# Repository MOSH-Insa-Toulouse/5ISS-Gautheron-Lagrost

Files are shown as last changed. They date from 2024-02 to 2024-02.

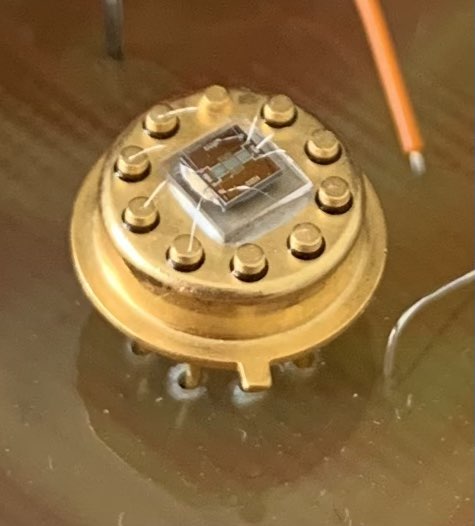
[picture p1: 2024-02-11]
__Images/sensor.jpg

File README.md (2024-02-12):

# Creating a shield to send data from a SGS24ISS gas sensor to a LoRaWAN Network

Authors: Arthur Gautheron, Olivier Lagrost

## 📝 Objectives and Block Diagram

The final objective of the Smart Devices UF is to "design and build a smart device based on the combination of a gas sensor and an electronic card to communicate information over a low speed network". It is a pluridisciplinary subject that combines skills from all educational backgrounds included in the PTP. GP (physics) students are best at designing a PCB and creating datasheets. AE (electronics) students, such as ourselves, prefer electrical schematics, embedded programming and have a better understanding of how to design the whole system overall. Finally, IR (computer science) students are better at understanding how to communicate data over LoRaWAN.

This repository aims at explaining our work on this system.

SGS24ISS is the name we decided to give to our homemade gas sensor. It stands for "Smart Gas Sensor 2024 Innovative Smart Systems". The objective of the project is to collect data from the smart sensor, monitor its internal temperature for optimal measurements, and send the collected data over LoRa to a Chirpstack server to be processed and used in an eventual application.

MOSH_diagram

## 🧑‍🔬 Sensor design and creation

sensor

The SGS24ISS gas sensor is capable of detecting the presence of several gases depending on their concentration. The sensor is able to perform multiple tasks:
* Returns current that depends on the concentration of gas around the sensor.
* Measure its own internal temperature.
* Increase its own temperature with an integrated heater.

For more information about the sensor, please read its datasheet [here](https://github.com/Timanoin/lora_app/blob/main/datasheet.pdf).

## 💻 Sensor Acquisition System



To collect data from the sensor, the current emitted by the sensor must be transformed into voltage, since MCUs cannot acquire current intensity. The system developed to acquire this information is a transimpedance amplifier.
The LTSpice directory contains the schematic of such an acquisition system, as well as other simulations to model the gas sensor.

The transimpedance amplifier is composed of 4 stages.
* Low-pass filter of cut-off frequency 16Hz to remove noise from the sensor.
* Low-pass filter of cut-off frequency 1.6Hz to remove noise from the mains supply.
* Non-inverting amplifier.
* Low-pass filter of cut-off frequency 1600Hz as an anti-aliasing filter.

The resistance of the gas sensor is determined as follows:


## ✏️ Shield Electrical Schematic



The schematics tested in simulation with LTSpice are recreated into KiCad for future PCB creation. All pins from the SGS24ISS (gas sensor, temperature sensor, heater) are connected to the Arduino pins. The RN2483 LoRa communication chip and its antenna are also connected to the Arduino in the schematic.
The KiCad files can be found here.

## ⚡ Shield PCB Design



The PCB is routed on the bottom layer, since pins of THT components must be soldered on the copper covered side of the PCB.

moshpcb

The resulting PCB is pretty small, but it could be even smaller if another MCU was used for data acquisition (like an Arduino Nano or a STM32).

## 💻 Arduino Uno Embedded Software



We first set up our LoRa communication and we initialize the pins for the sensor and the Uart to communicate with our chip. Thus we have two serial communications, “Serial” between the computer and the Arduino and “mySerial” between the Arduino and the RN2483A. We also define the threshold on the sensor value above which we start transmitting our data, meaning that the gas quantity is dangerous. 



In order to communicate by LoRa we have to set it up. We wait for our RN2483A to start and check if we can communicate by LoRa. To this end, we print the Hardware EUI (HWEUI) which is the ID of our RN2483 and that we need to register our device on Chirpstack. 



We now have to establish communication with Chirpstack using the Over The Air Authentication (OTAA) method to connect to the network. To this end, we need the appEui and the appKey found on the Chirpstack website when registering our device. and the function ”initOTAA(appEui, appKey)” to connect. 

## 📻 ChirpStack





On the Chirp Stack side, we create a profile and add a device to get the JoinEui ( = appEui) and the appKey. 
Once we are connected we can start sending the data from our sensor. 
As specified at the beginning, we only send data when an overshoot to the threshold happens. 



We can see that we are connected to Chirpstack, our device is enabled and sending data in ASCII

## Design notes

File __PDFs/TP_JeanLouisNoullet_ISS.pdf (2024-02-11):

# ISS - UF Smart Devices : partie analogique

English version here

## 1. Mesure d'une résistance

Méthodes classiques :

- imposer I, mesurer V
- imposer V, mesurer I
- alimenter, mesurer V et I
- alimenter, mesurer R par identification (pont)

Cas du capteur de gaz à nano-particules :

- très faible courant : de l'ordre de 100 nA
- effet tunnel : forte non-linéarité de I(V)

Alors quelle technique adopter pour extraire l'information utile du capteur ?

## 2. Mesure de faible courant avec un micro-contrôleur

Parametres des microcontrôleurs courants en 2016
(AVR/Arduino, STM32, PIC Microchip, etc...) :
- résolution 10 à 12 bits (1024 à 4096 points)
- pleine échelle (VRef) de 1.1 V à 5.0 V
- impédance de source max 1 kOhm à 10 kOhm
- fréquence d'échantillonnage max 15 kHz à 2.4 MHz
La mesure directe d'un courant de 100 nA ne parait pas praticable.
N.B. la valeur max d'impédance de source est spécifiée en fonction de l' échantillonneur à capacité commutée présent à l'entrée de l'ADC.

Solution "classique" :

L'amplificateur transimpédance.

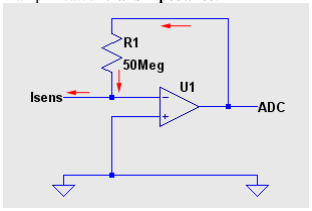
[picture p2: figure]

Problèmes posés par cette solution :

- nécessite une très grande valeur pour R1
- nécessite une tension négative pour alimenter le capteur

Solution "classique" améliorée :

L'amplificateur transimpédance suivi d'un étage amplificateur inverseur.

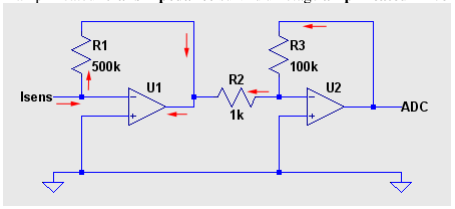
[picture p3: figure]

- grâce au gain du second étage, la résistance R1 n'a pas besoin d'être grande
- grâce à l'inversion, l'alimentation du capteur peut être positive
- cependant il faut une alimentation bipolaire pour les amplis

Solution minimaliste :

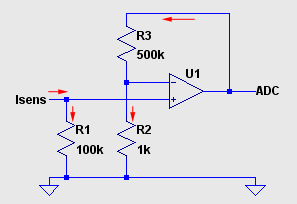
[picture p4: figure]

- conversion I-->U dans la résistance d'épreuve R1 (shunt)
- amplification à fort gain par montage non-inverseur
- la chute de tension sur R1 perturbe (un peu) la tension appliquée au capteur
- peut fonctionner avec seulement une alimentation positive

Remarques :
Gain de l’étage de l’AOP : (R2+R3)/R2=(1k+500k)/1k=501
Tension aux bornes de R1 : le courant Isens est d’environ 100nA
- V = 100kOhm*100nA=10⁻²V=10mV
Tension sur l’ADC : Gain*Tension aux bornes de R1 => 501*10x10⁻³~5V

Contraintes sur le choix de l'ampli :

- faible courant d'entrée

- ultra-faible offset de tension
- supporte mode commun à la tension d'alim négative ("low rail")

Remarques :
(1) offset voltage = erreur constante aux entrées de l’amplificateur différentiel dû à un état non compensé sur l’étage d’entrée de l’amplificateur. On veut que cet offset soit négligeable devant la tension mesurée sur R1 qui sera de 10mV.
(2) Le courant d’entrée doit être très petit devant Isens pour avoir le Isens traverse la R1 et pas l’entrée
(3) Mode commun : tension commune aux deux entrées, un bon amplifieur sera insensible à ce mode commun. Si le Isens =0A ,on veut 0V sur l’ADC. LTC1050C => 5µV offset voltage, et maximum offset voltage drift : 0.05µV/°C. Bien comparé aux 10mV aux bornes de R1.

L'ampli LTC1050C est disponible, satisfait-il ces contraintes ?

## 3. Filtrage passe-bas

Une bande passante de l'ordre de 1 Hz est largement suffisante pour extraire toute l'information utile du capteur, dont l'inertie est importante.

Un montage aussi sensible étant très vulnérable au bruit à 50Hz (+ harmoniques) résultant du couplage capacitif avec le réseau 230V, un filtrage passe-bas est indispensable.
D'autres sources de bruit à filtrer sont les horloges de circuits digitaux (microcontrôleur, afficheurs, etc...) et les transceivers RF (bluetooth, etc...).

Ce filtrage peut être effectué en partie du coté digital, par programme, sur le microcontrôleur.
Cependant un filtrage analogique est indispensable, en effet un excès de bruit à l'entrée de l'ADC pourrait amener celui-ci à saturation.
De plus un filtrage anti-repliement (anti-aliasing) est indispensable en raison de l'échantillonnage effectué par l'ADC.
Pour faciliter ce filtrage on a intérêt à faire fonctionner l'ADC à la plus GRANDE fréquence utilisable SANS PERTE DE QUALITE (dans le cas de l'Arduino Uno, 200kHz/13 = 15.4 kHz, avec un choix de prescaler à 128 ! (cf wiring.c).

Le filtrage peut s'implanter dans 3 régions de la chaîne de traitement analogique :

- filtre passif à l'entrée : permet d'éviter que les bruits HF causent de la distorsion dans les étages d'entrée
- filtre actif basé sur les amplificateurs opérationnels : maximum d'efficacité
- filtre passif en fin de chaine, coté ADC, pour retirer le bruit introduit en cours de traitement (bruit d'alimentation, bruit d'horloge des amplificateurs à découpage)

Schéma Suggéré

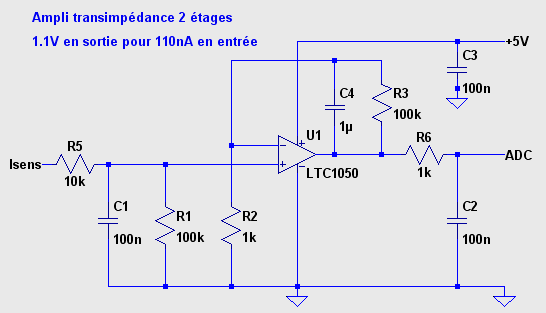
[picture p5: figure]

- R5 en entrée protège l'ampli opérationnel contre les décharges électrostatiques, en forme avec C1 un filtre pour les bruits en tension
- C1 avec R1 forme un filtre pour le bruit en courant
- R2 sera interchangeable, pour permettre une adaptation du calibre
- C4 avec R3 forme un filtre actif
- C2 avec R6 forme le filtre de sortie
- C3 filtre le bruit d'alimentation

## 4. Questions

A l’aide du simulateur LTSpice IV :

1. Vérifier la fonctionnalité dans les conditions nominales 2. L'incidence de l'offset de l'amplificateur LTC1050C est-elle acceptable ? 3. L'incidence du courant d'entrée de l'amplificateur est-elle acceptable ? 4. Quelle est la fréquence de coupure de chaque étage de filtre passe-bas ? 5. Quelle est l'atténuation globale d'un bruit en courant de 50 Hz ?

6. Quelle est l'atténuation globale d'un bruit en courant à la fréquence limite de repliement (dans le cas de l'ADC Arduino Uno) ?

### 7. Préparez une simulation de démonstration avec :

- un capteur alimenté en 5V dont la conductance varie de 10 nS à 20 nS en 0.5s (l’utilisation d’un filtre passe-bas pourrait être utile !).

### 1. Mettre en évidence l’intérêt du filtrage 50Hz choisi en visualisant

l’impact d’un bruit de 1% sur la source d’alimentation du capteur

### 2. Quand est-ce que ce bruit devient gênant ?

- Pour s’approcher des conditions réelles de mesures réalisées à l’AIME, vous modifierez le montage précédent pour mettre une alimentation de 20V sur le capteur (à la place de la 5V) et conserverez l’alimentation de 5V sur l’AOP.

### 1. Peut-on réaliser ce montage sur un Arduino Uno ?

- une source de bruit de 230V RMS à 50Hz, couplée au noeud d'entrée par une capacité de 1 pF
- Serait-il intéressant d’ajouter un montage dérivateur pour mesurer directement le coefficient cinétique de la réaction chimique du capteur avec un gaz ?

### 1. Si oui, proposez un montage !

N.B. pour simuler une conductance variable, utiliser l'élément Arbitrary current source (symbole BI) de LTSpice contrôlé par une source de tension indépendante représentant la variation de concentration du gaz atteignant le capteur

8. Donner une expression analytique de la résistance du capteur en fonction des éléments du circuit transimpédance.

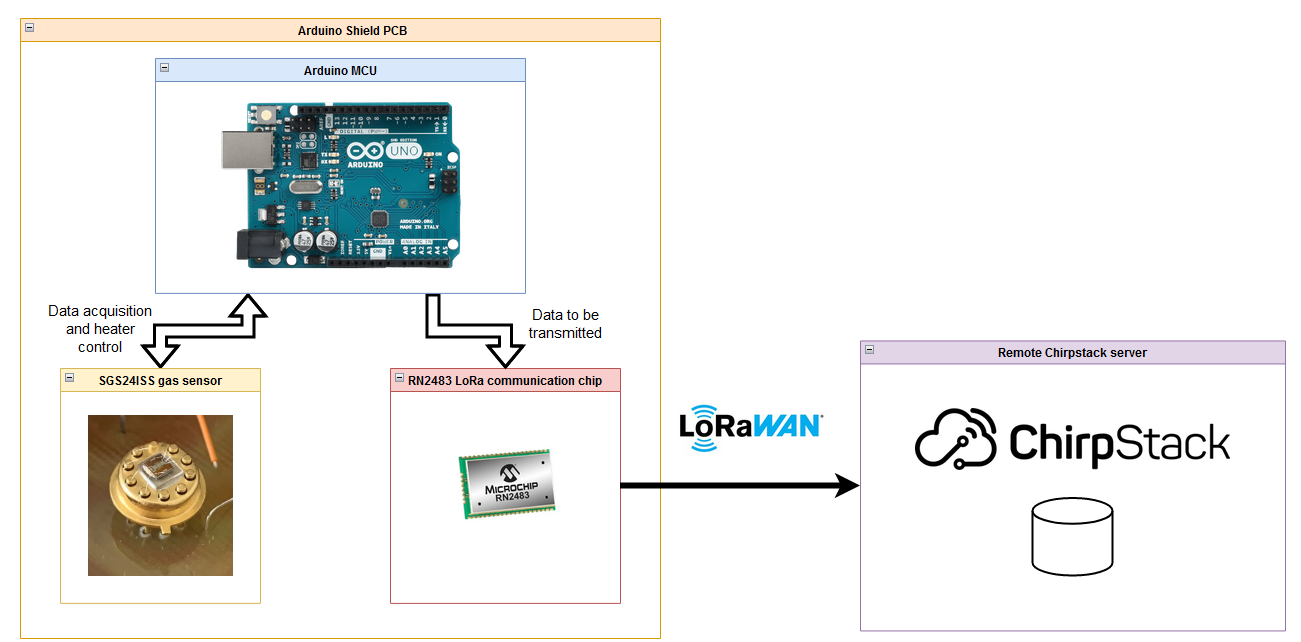
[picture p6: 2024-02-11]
__Images/MOSH_diagram.png

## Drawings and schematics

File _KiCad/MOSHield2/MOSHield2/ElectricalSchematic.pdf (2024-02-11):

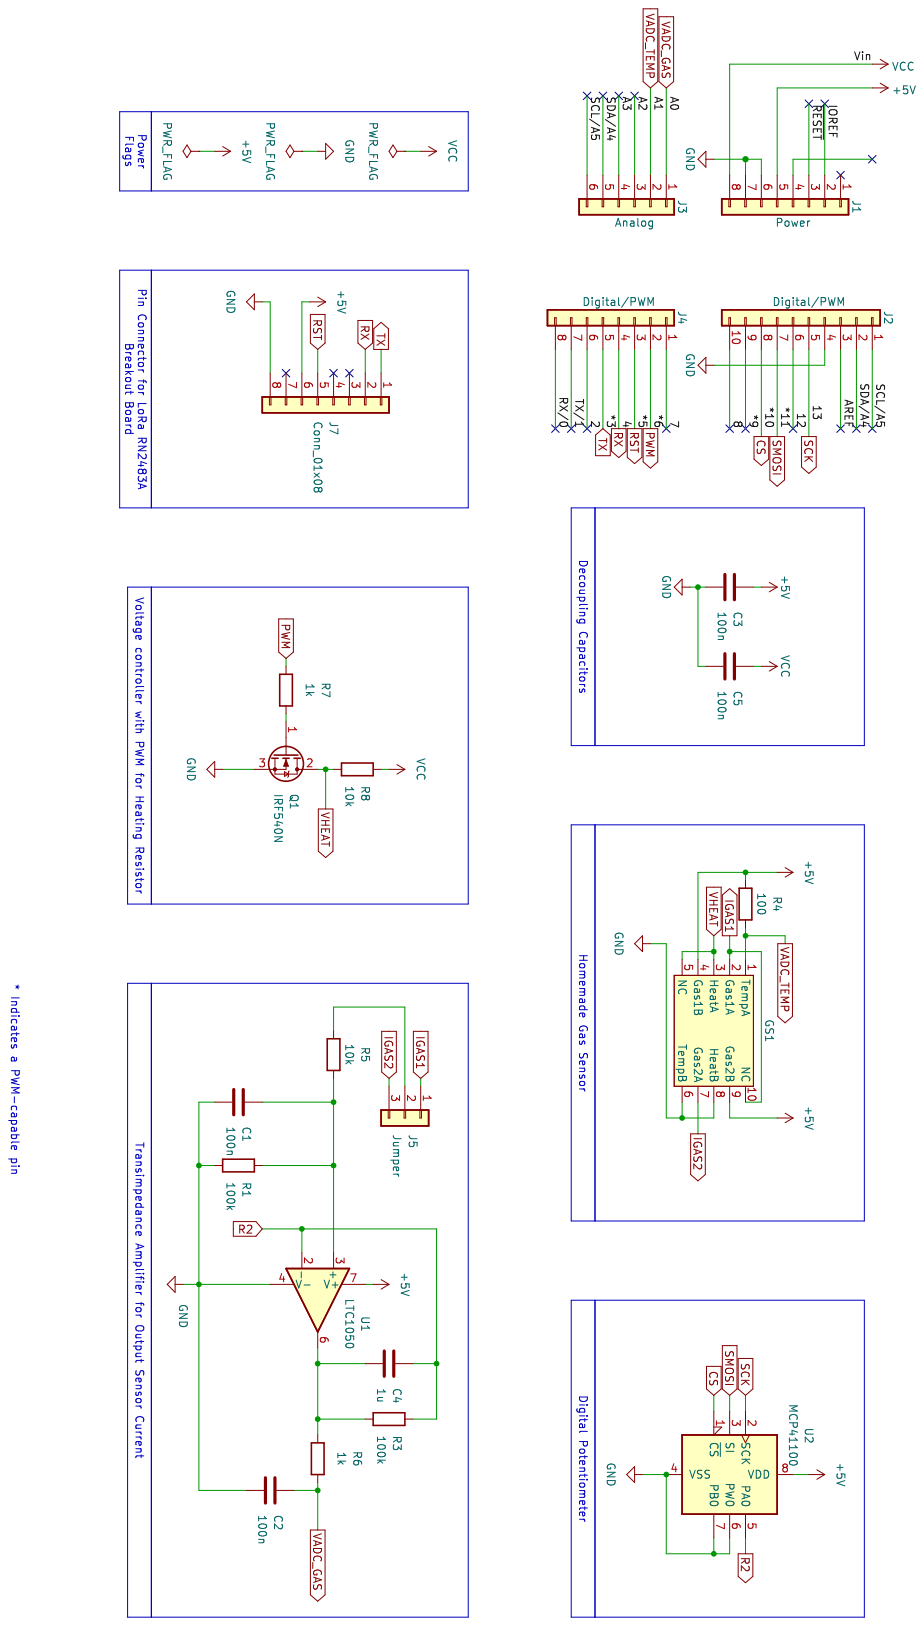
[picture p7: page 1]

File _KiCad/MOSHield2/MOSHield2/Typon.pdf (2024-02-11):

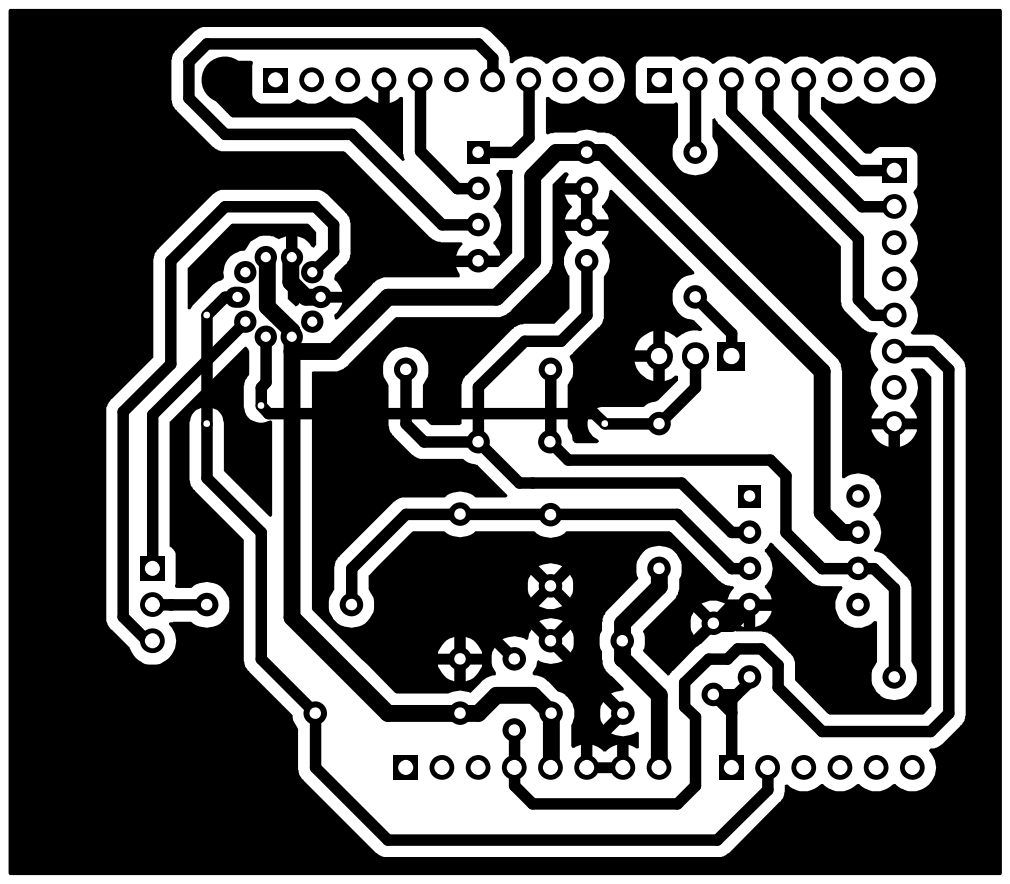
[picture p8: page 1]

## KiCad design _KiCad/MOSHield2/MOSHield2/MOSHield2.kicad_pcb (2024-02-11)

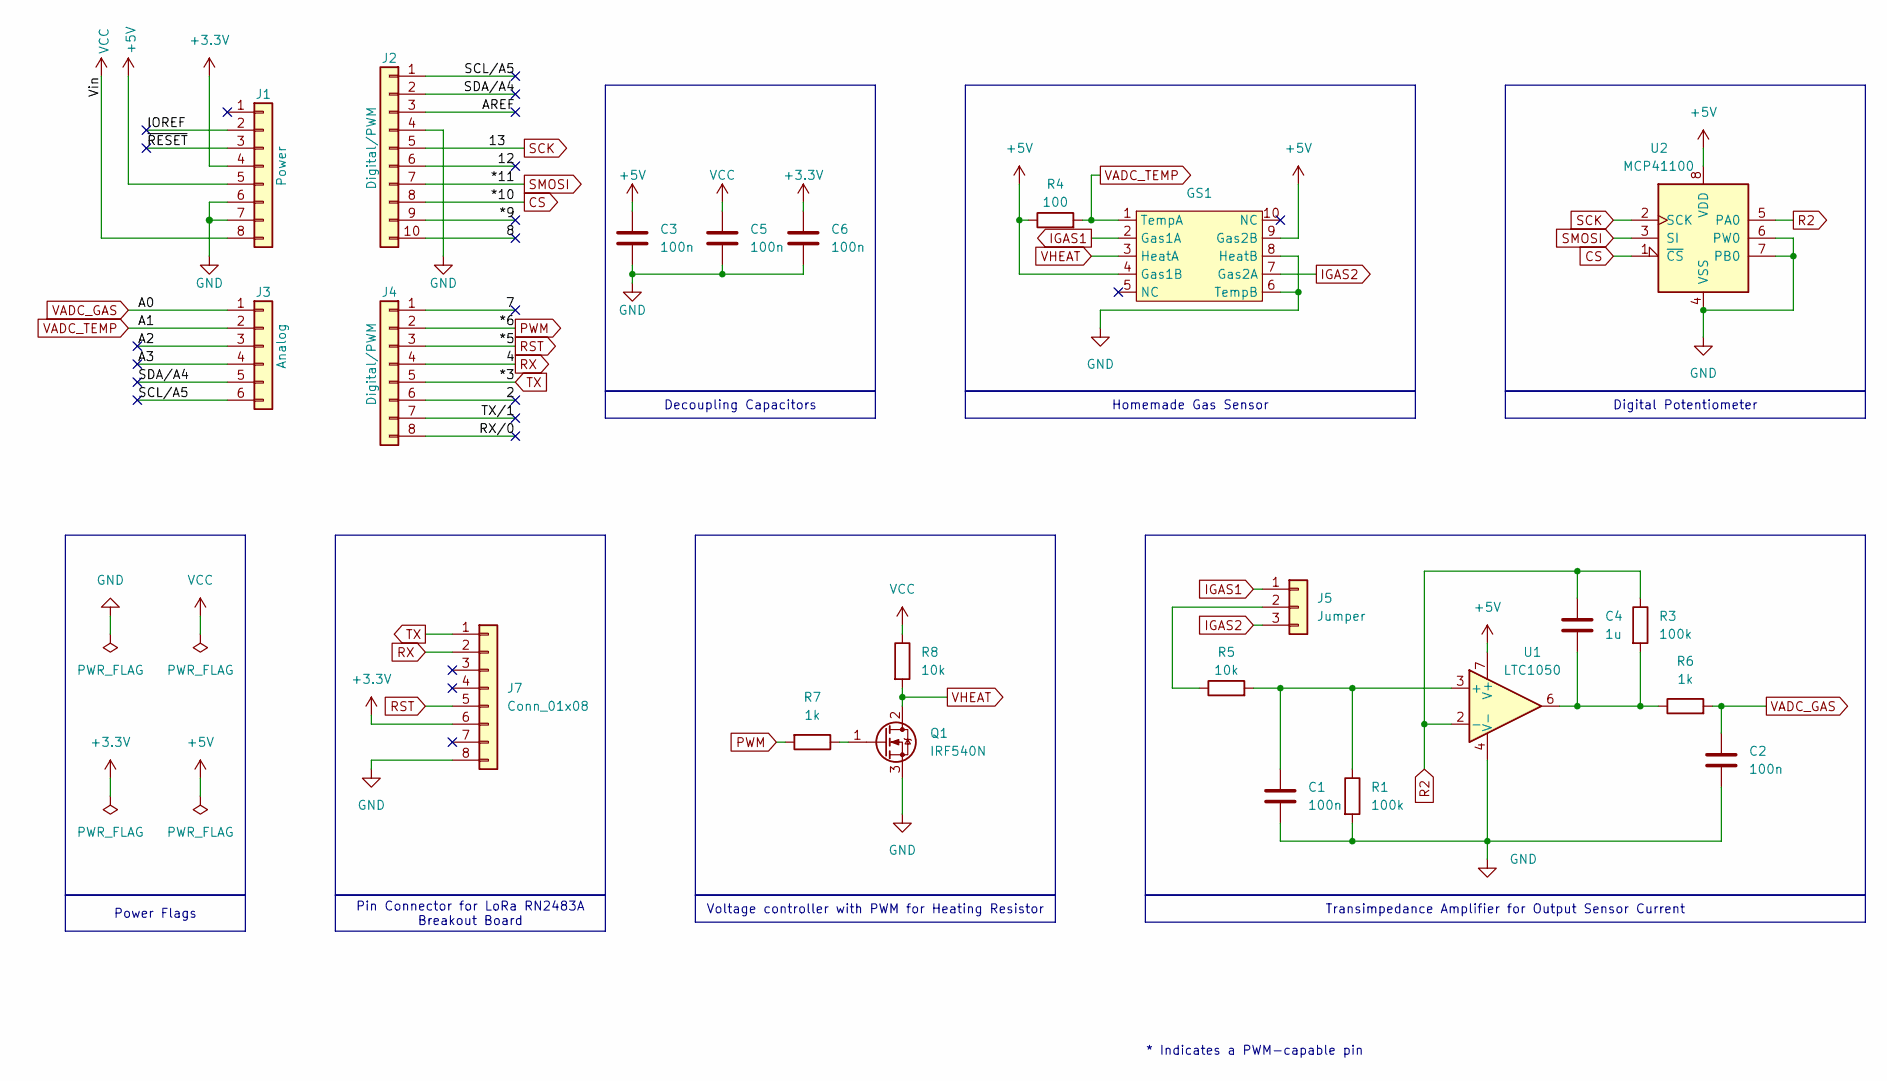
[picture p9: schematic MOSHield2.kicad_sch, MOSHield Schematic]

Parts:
C1, C2, C3, C5, C6: 100n; C_Disc_D4.7mm_W2.5mm_P5.00mm
C4: 1u; C_Rect_L7.0mm_W4.5mm_P5.00mm
GS1: TO-5-10
J1: Power; PinSocket_1x08_P2.54mm_Vertical
J2: Digital/PWM; PinSocket_1x10_P2.54mm_Vertical
J3: Analog; PinSocket_1x06_P2.54mm_Vertical
J4: Digital/PWM; PinSocket_1x08_P2.54mm_Vertical
J5: Jumper; PinHeader_1x03_P2.54mm_Vertical
J7: Conn_01x08; PinSocket_1x08_P2.54mm_Vertical
Q1: IRF540N; TO-220-3_Vertical
R1, R3: 100k; R_Axial_DIN0207_L6.3mm_D2.5mm_P10.16mm_Horizontal
R4: 100; R_Axial_DIN0207_L6.3mm_D2.5mm_P10.16mm_Horizontal
R5, R8: 10k; R_Axial_DIN0207_L6.3mm_D2.5mm_P10.16mm_Horizontal
R6, R7: 1k; R_Axial_DIN0207_L6.3mm_D2.5mm_P10.16mm_Horizontal
U1: LTC1050; DIP-8_W7.62mm
U2: MCP41100; DIP-8_W7.62mm

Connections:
+3.3V: C6.1, J1.4, J7.6
+5V: C3.1, GS1.4 (Gas1B), GS1.9 (Gas2B), J1.5, R4.1, U1.7 (V+), U2.8 (VDD)
/2: J4.6
/7: J4.1
/8: J2.10
/12: J2.6
/*9: J2.9
/A2: J3.3
/A3: J3.4
/AREF: J2.3
/IOREF: J1.2
/RX/0: J4.8
/SCL/A5: J2.1, J3.6
/SDA/A4: J2.2, J3.5
/TX/1: J4.7
/~RESET: J1.3
CS: J2.8, U2.1 (~CS)
GND: C1.2, C2.2, C3.2, C5.2, C6.2, GS1.6 (TempB), GS1.8 (HeatB), J1.6, J1.7, J2.4, J7.8, Q1.3 (S), R1.2, U1.4 (V-), U2.4 (VSS), U2.6 (PW0), U2.7 (PB0)
IGAS1: GS1.2 (Gas1A), J5.1
IGAS2: GS1.7 (Gas2A), J5.3
unnamed: C4.2, R3.2, R6.1, U1.6
unnamed: J5.2, R5.1
unnamed: Q1.1 (G), R7.1
unnamed: C1.1, R1.1, R5.2, U1.3 (+)
PWM: J4.2, R7.2
R2: C4.1, R3.1, U1.2 (-), U2.5 (PA0)
RST: J4.3, J7.5
RX: J4.4, J7.2
SCK: J2.5, U2.2 (SCK)
SMOSI: J2.7, U2.3 (SI)
TX: J4.5, J7.1
VADC_GAS: C2.1, J3.1, R6.2
VADC_TEMP: GS1.1 (TempA), J3.2, R4.2
VCC: C5.1, J1.8, R8.1
VHEAT: GS1.3 (HeatA), Q1.2 (D), R8.2

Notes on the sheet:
Decoupling Capacitors
Homemade Gas Sensor
Transimpedance Amplifier for Output Sensor Current
Power Flags
Voltage controller with PWM for Heating Resistor
Pin Connector for LoRa RN2483A Breakout Board
Digital Potentiometer
* Indicates a PWM-capable pin

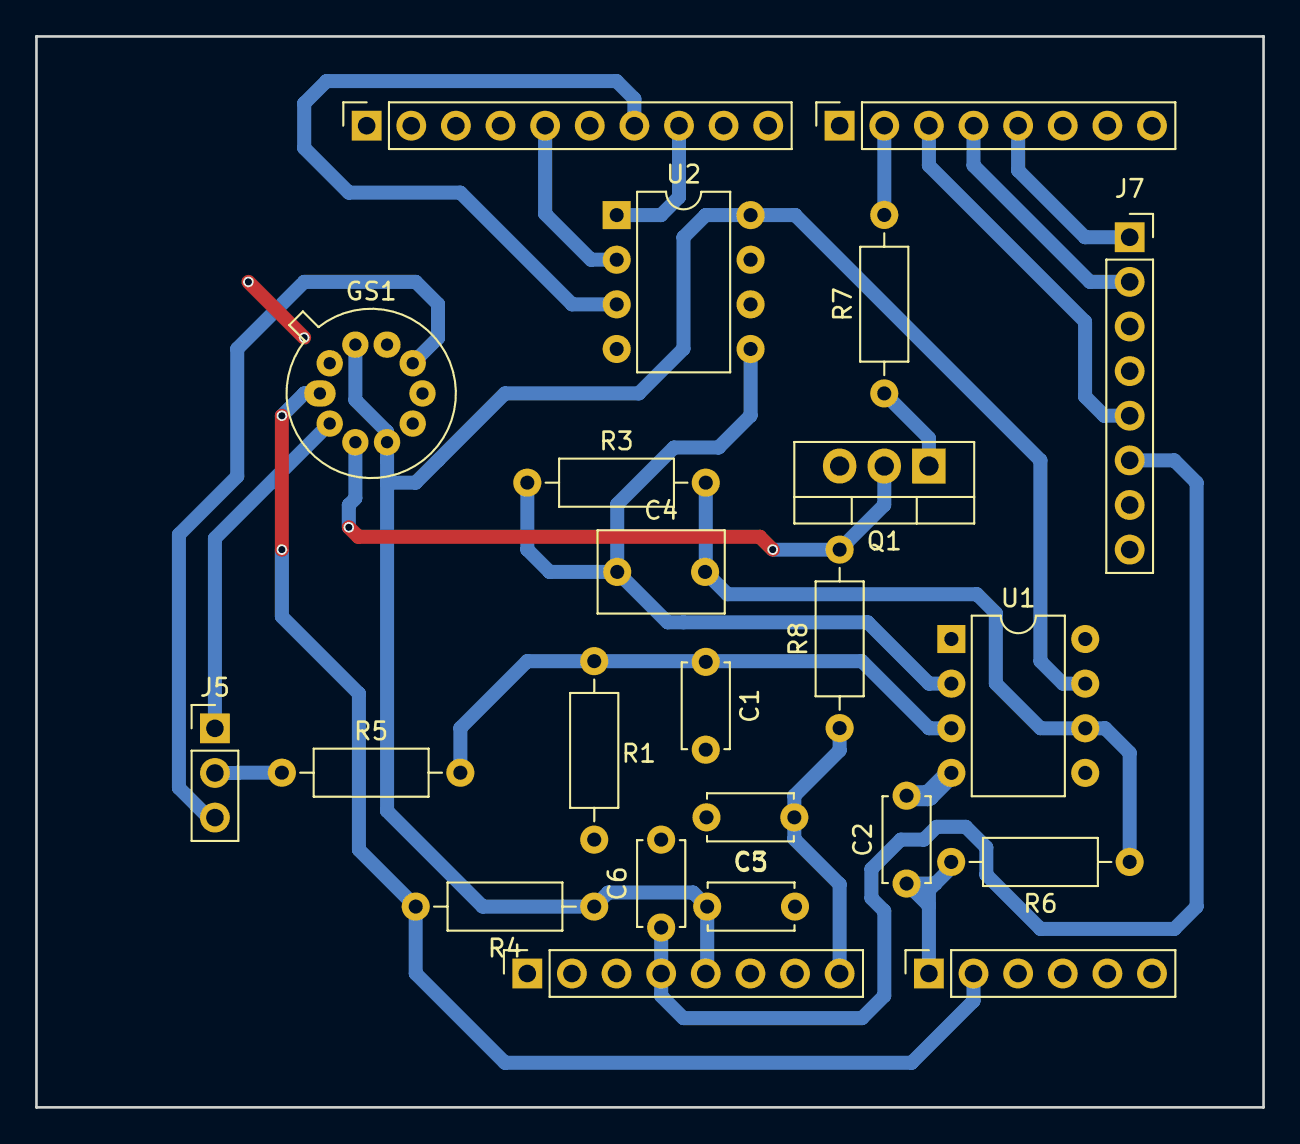
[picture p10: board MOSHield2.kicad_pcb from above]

Board: 2 copper layers, 69.8 x 61.0 mm, 23 parts (0 on the bottom side), 23 nets.

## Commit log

2023-12-06 Added Arduino and KiCad projects
    [MOSHield.kicad_pcb, MOSHield.kicad_sch]
2024-02-11 Added datasheet
    [MOSHield-B_Cu.gbr, MOSHield-B_Silkscreen.gbr, MOSHield-Edge_Cuts.gbr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]
2024-02-11 Almost final commit
    [MOSHield-B_Cu.gbr, MOSHield-B_Silkscreen.gbr, MOSHield-Edge_Cuts.gbr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]
